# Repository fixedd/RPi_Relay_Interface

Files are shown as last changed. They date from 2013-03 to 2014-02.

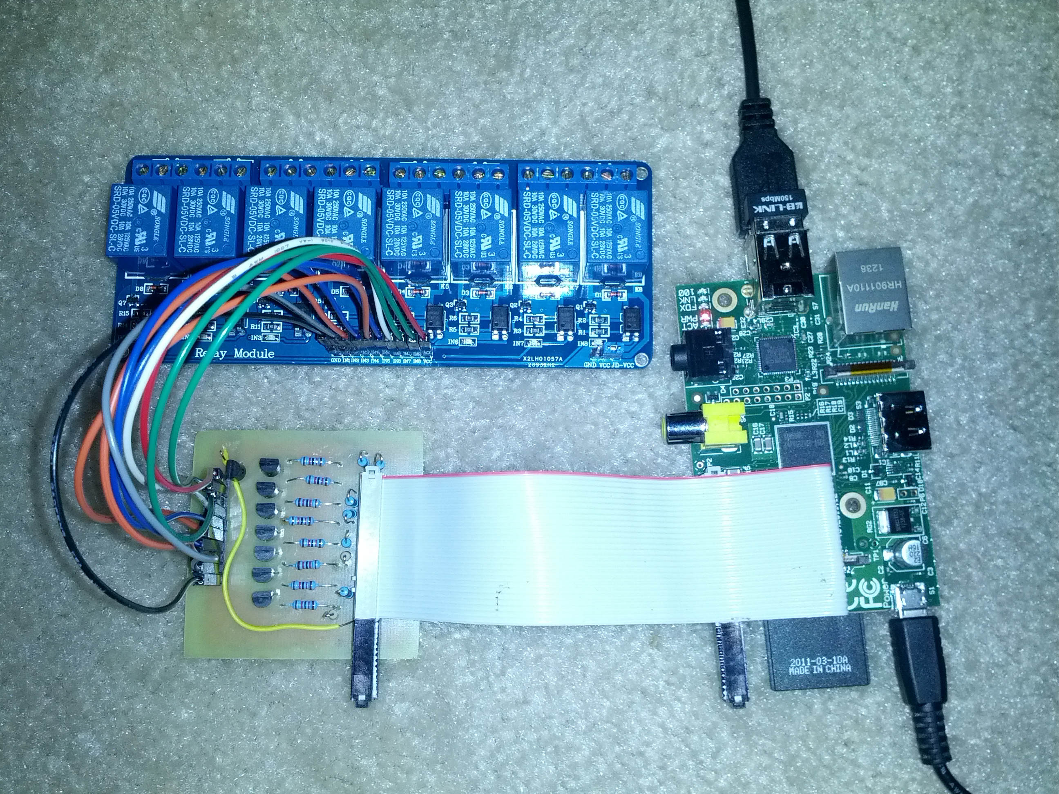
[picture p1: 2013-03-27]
images/whole_setup.jpg

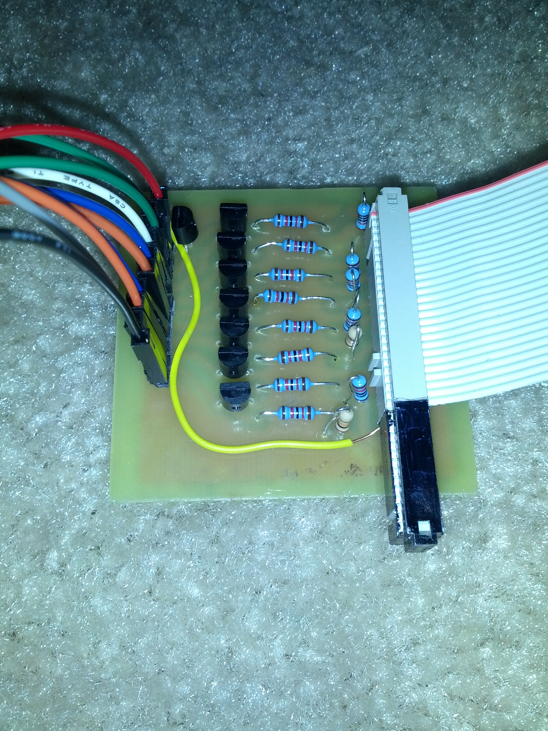
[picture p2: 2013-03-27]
images/closeup.jpg

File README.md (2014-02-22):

# Raspberry Pi Relay Module Interface Board

## Note / Warning

This was formerly stated to be for the SainSmart relay modules, but it was later pointed out to me that these boards actually already have this logic built in to them. 

## Overview

These interface boards will allow you to connect your [Raspberry Pi](http://www.amazon.com/gp/product/B009SQQF9C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) (rev 2.0, at least) to a 4 or 8-Channel 5V Relay Module.

## Parts List
### 8-Channel 5V Relay Module

| Quantity | Part | Notes |
| :---: | --- | ----- |
| 8 | 12kΩ ¼ Watt Resistors | [This multi-pack](http://www.amazon.com/gp/product/B003UC4FSS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) has all the resistors you'll need for this, and much more. |
| 8 | 10kΩ ¼ Watt Resistors | |
| 8 | 2N3904 Transistors | [Amazon](http://www.amazon.com/gp/product/B00AUEFGU0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). |
| 1 | 2 inch x 2 inch single-sided PCB | I cut [this](http://www.amazon.com/gp/product/B000P7ALZC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) down. |
| 1 | 3 inch jumper wire | |
| 1 | 26 pin header (2x13) | [This] will be more than enough. |
| 1 | 10 pin header (1x10) | |

### 4-Channel 5V Relay Module
| Quantity | Part | Notes |
| :---: | --- | ----- |
| 4 | 12kΩ ¼ Watt Resistors | [This multi-pack](http://www.amazon.com/gp/product/B003UC4FSS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) has all the resistors you'll need for this, and much more. |
| 4 | 10kΩ ¼ Watt Resistors | |
| 4 | 2N3904 Transistors | [Amazon](http://www.amazon.com/gp/product/B00AUEFGU0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). |
| 1 | 2 inch x 2 inch single-sided PCB | I cut [this](http://www.amazon.com/gp/product/B000P7ALZC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) down. |
| 1 | 3 inch jumper wire | |
| 1 | 26 pin header (2x13) | [This] will be more than enough. |
| 1 | 10 pin header (1x10) | |

## Explanation

The relay boards are powered by 5v and the relays are triggered by taking the input pin to ground. Since the Raspberry Pi's GPIO pins output 3.3v I used a set of transistors to take the relay pins to ground.

I used 2N3904 transistors simply because they were cheap and readily available. In theory any NPN transistor should work, but the resistors may need to be adjusted.

To make the board I used the toner transfer method. There are [plenty of instructions](http://www.instructables.com/id/Cheap-and-Easy-Toner-Transfer-for-PCB-Making/) on the internet for this, so I won't go into it here.

The Relay Module I used has opto-isolation on the input pins. To maintain this isolation you would need to use an external 5v power supply instead of using the Pi's.

### Files

* ```eagle_files``` - Provided here are [Eagle PCB](http://www.cadsoftusa.com/eagle-pcb-design-software/) schematic and layout files.
* ```gerber_files``` - these are [Gerber format](http://en.wikipedia.org/wiki/Gerber_format) files so it will be easy to have boards manufactured.
* ```images``` - Images of my board and the files I printed to do the toner transfer.
* ```test_scripts``` - Some python scripts to test the operation of the board.

## Video



## Thanks

* Thanks to the folks on the [Raspberry Pi BB](http://www.raspberrypi.org/phpBB3/viewtopic.php?t=19222), without their guidance it would have taken me longer to figure this out.
* Thanks to @lazylester for the Gerber files for the 8-channel version.
* Thanks to @fjung for the Eagle and Gerber files for the 4-channel version.

## License

There is no license other than to say that I release this to the public domain... do with it as you wish (see [the license file](./LICENSE.md)).

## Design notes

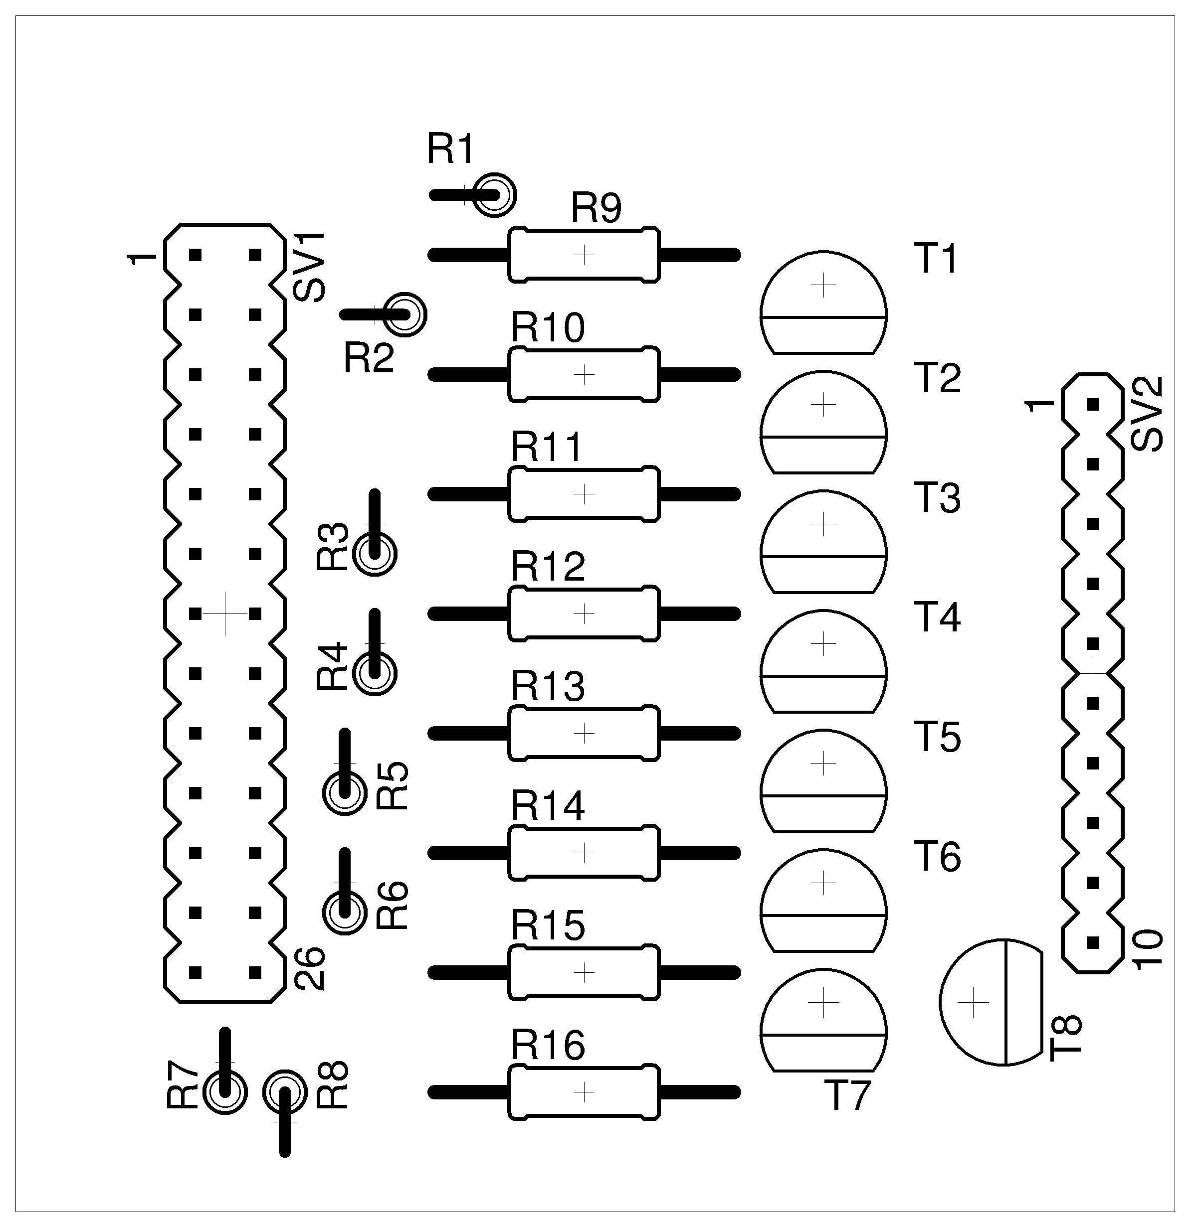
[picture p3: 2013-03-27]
images/board_labels.png

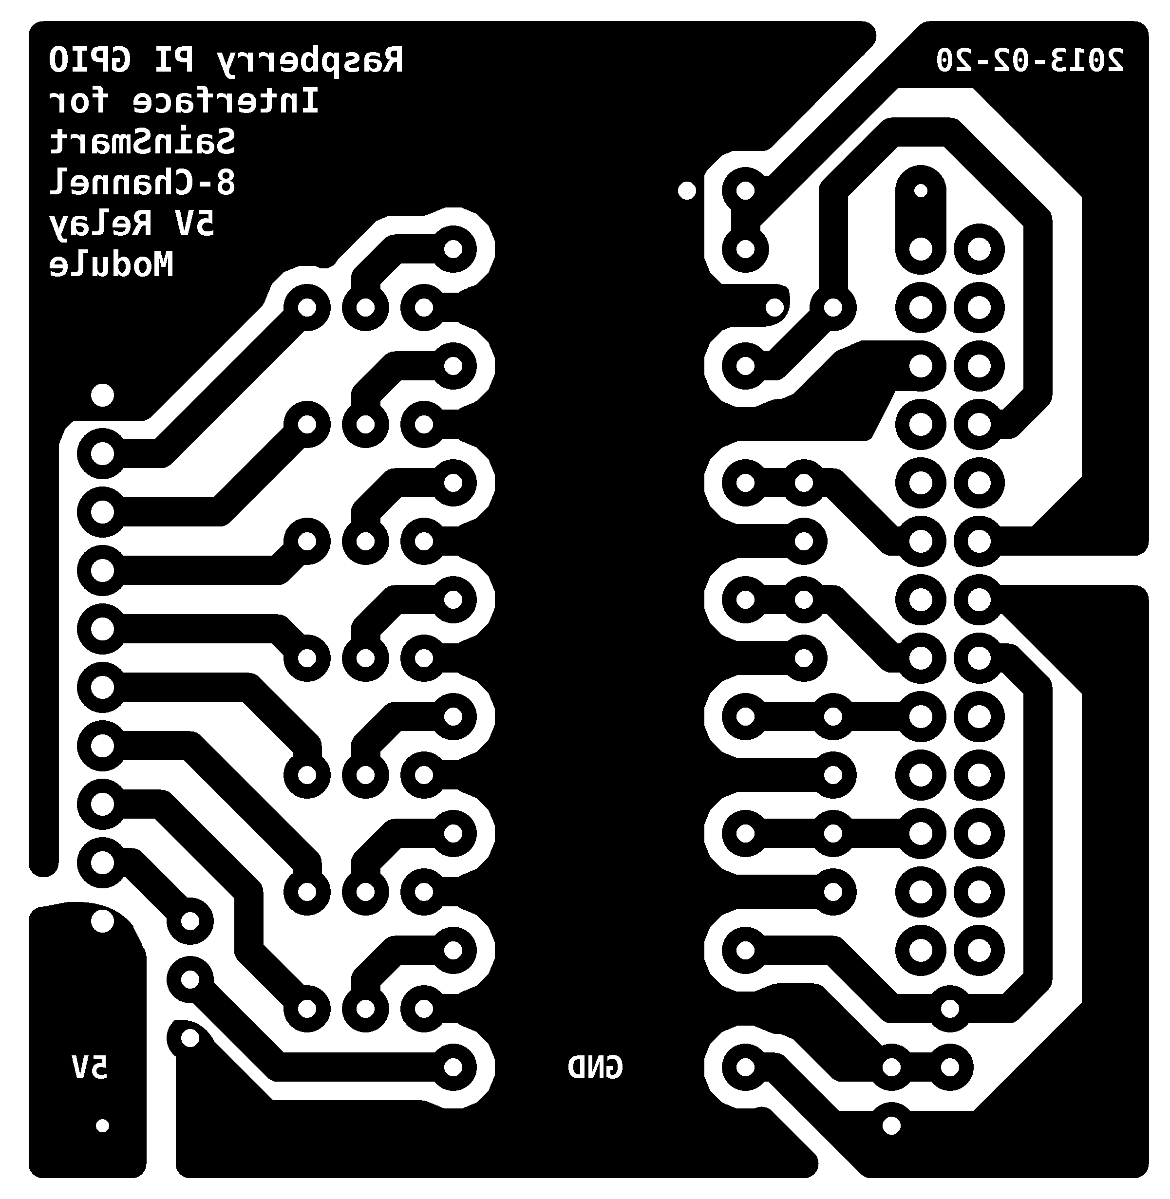
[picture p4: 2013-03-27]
images/board.png

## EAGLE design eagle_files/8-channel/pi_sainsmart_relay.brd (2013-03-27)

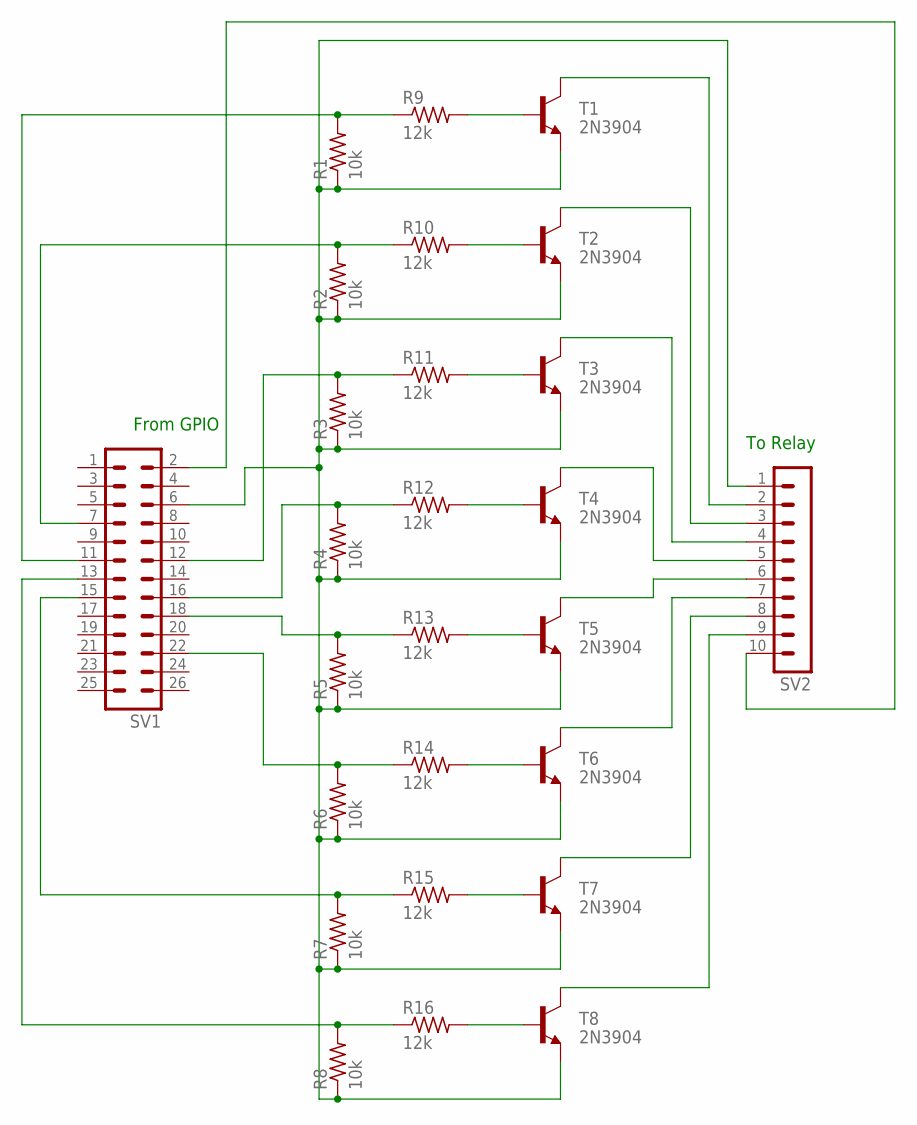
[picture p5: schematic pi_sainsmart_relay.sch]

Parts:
R1, R2, R3, R4, R5, R6, R7, R8: 10k; 0204V
R9, R10, R11, R12, R13, R14, R15, R16: 12k; 0207/12
SV1: MA13-2
SV2: MA10-1
T1, T2, T3, T4, T5, T6, T7, T8: 2N3904; TO92-EBC

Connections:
AAA: R8.2, R16.1, SV1.13
BBB: R1.2, R9.1, SV1.11
FIVEV: SV1.2, SV2.10
GND: R1.1, R2.1, R3.1, R4.1, R5.1, R6.1, R7.1, R8.1, SV1.6, SV2.1, T1.E, T2.E, T3.E, T4.E, T5.E, T6.E, T7.E, T8.E
unnamed: R16.2, T8.B
unnamed: R15.2, T7.B
unnamed: R14.2, T6.B
unnamed: R13.2, T5.B
unnamed: R12.2, T4.B
unnamed: R11.2, T3.B
unnamed: R10.2, T2.B
unnamed: R9.2, T1.B
unnamed: SV2.3, T2.C
unnamed: SV2.4, T3.C
unnamed: SV2.5, T4.C
unnamed: SV2.6, T5.C
unnamed: SV2.7, T6.C
unnamed: SV2.8, T7.C
unnamed: SV2.2, T1.C
unnamed: SV2.9, T8.C
unnamed: R3.2, R11.1, SV1.12
unnamed: R4.2, R12.1, SV1.16
unnamed: R5.2, R13.1, SV1.18
unnamed: R6.2, R14.1, SV1.22
unnamed: R2.2, R10.1, SV1.7
unnamed: R7.2, R15.1, SV1.15

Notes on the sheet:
To Relay
From GPIO

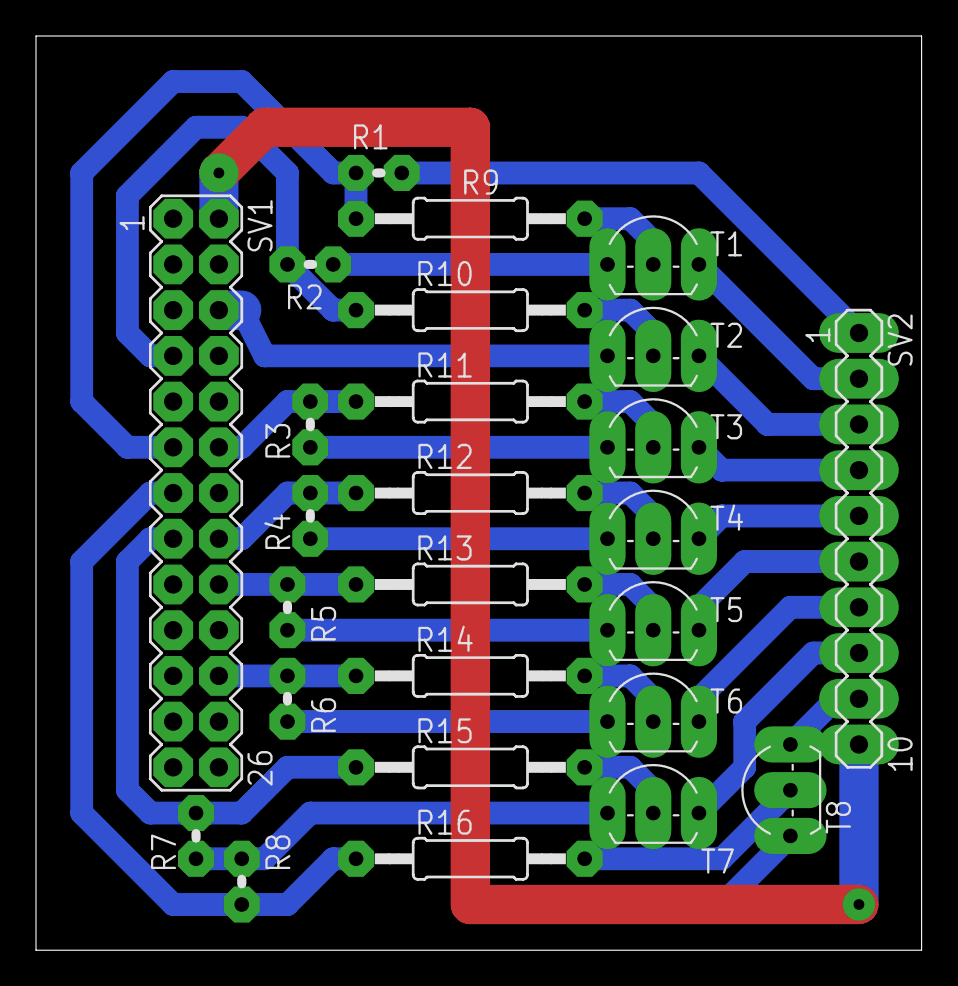
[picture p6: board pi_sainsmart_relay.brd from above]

Board: 2 copper layers, 49.2 x 50.8 mm, 26 parts (0 on the bottom side), 26 nets.

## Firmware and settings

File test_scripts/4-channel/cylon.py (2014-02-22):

#! /usr/bin/python
import RPi.GPIO as GPIO
import time


sleep_time = 0.05
relay_pins = {'one': 12, 'two':16, 'three':18, 'four':22}



def float_pin(off, on):
	if (on != None):
		GPIO.output(on, GPIO.HIGH)
		time.sleep(sleep_time);
	if (off != None):
		GPIO.output(off, GPIO.LOW)
		time.sleep(sleep_time);



GPIO.setmode(GPIO.BOARD)  # use P1 header pin numbering convention
GPIO.setwarnings(False)   # don't want to hear about how pins are already in use



for relay_pin, board_pin in relay_pins.iteritems():
	GPIO.setup(board_pin, GPIO.OUT, GPIO.LOW)
	GPIO.output(board_pin, GPIO.LOW)

for b in xrange(2):
	float_pin(None	             , relay_pins['one']  )
	float_pin(relay_pins['one']  , relay_pins['two']  )
	float_pin(relay_pins['two']  , relay_pins['three'])
	float_pin(relay_pins['three'], relay_pins['four'] )
	float_pin(relay_pins['four'] , relay_pins['three'])
	float_pin(relay_pins['three'], relay_pins['two']  )
	float_pin(relay_pins['two']  , relay_pins['one']  )
	float_pin(relay_pins['one']  , None               )

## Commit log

2013-07-06 adds gerber files
2013-08-09 Added description of gerber_files directory to README.
2014-02-22 added Sainsmart 4-Channel 5V Relay Module
    [pi_sainsmart_relay_4.brd, pi_sainsmart_relay_4.sch]
2014-02-22 trying to organize 4-channel vs 8-channel
    [pi_sainsmart_relay.brd, pi_sainsmart_relay.sch]
